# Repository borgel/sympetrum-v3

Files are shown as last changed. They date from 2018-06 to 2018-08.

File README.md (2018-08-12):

# What?
An electronic conference badge, of course! (That makes this a wearable right?)

If you're interested in keeping up to date with new versions, you can add your email here: 
https://goo.gl/forms/xGFPdRpdT4x1kmzG3 I'll send out (few) updates as I make progress towards whatever the next version is.

## Yes, but what does it do?
By default the device does pleasant RGB fades across its 48 RGB LEDs. It also sends a beacon in infrared every 30 seconds. They use any beacons received to synchronize a clock from which an animation is derived. The effect is that if one is alone, it plays random colors. If a group of them are together, they play the same rainbow water drop animation together.

For a little more information, last year's was [written up by Hackaday here](https://hackaday.com/2017/07/14/badge-from-diamond-age-comes-to-def-con/).

This is a partial rewrite of the work done for [DEFCON](https://defcon.org/) 25 ([here](https://github.com/borgel/sympetrum-v2)).

## Why is it a dragonfly?
If you haven't read Neal Stephenson's [_The Diamond Age: or, A Young Lady's Illustrated Primer_](http://www.goodreads.com/book/show/827.The_Diamond_Age), do that first. I'll wait.

If you have, there's a sequence around page 300 in which Miranda is first introduced to the possibility of using the drummers to find Nell. In this scene she attends a party in which the revellers wear colorful cloisonné dragonfly pins. As the party progresses they transition from random colorful flickering to some sort of synchrony, and Miranda notices the participants do the same. This is what I built.

A [_Sympetrum_](https://en.wikipedia.org/wiki/Sympetrum) is a genus of Dragonfly.

# Addons
Assembly instructions here: https://docs.google.com/document/d/1MZ-Gf56ivJ_pZaOBdA2XsJtWuKzQMPqqDXrGzq-pdRY/edit?usp=sharing

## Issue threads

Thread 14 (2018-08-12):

USB header for power?

f1ana, 2018-08-12:
Hi,

Do you have instructions for providing power to the dragonfly via usb?  Pretty new to this, so not sure where to start!

Thanks,
Chris

f1ana, 2018-08-14:
Hi!  I thought that this might be a great night light for my daughter and to perhaps change the LED patterns down the road.  I've only got a software background and very little to no hardware, so I'm not sure what the best/proper way to accomplish this would be.

borgel, 2018-08-15:
Oh, that's a great idea! I think it shouldn't be too bad. Do you have access to a soldering iron?

borgel, 2018-08-15:
I think you could remove the battery holder and install something like this https://www.sparkfun.com/products/8376 in it's place, wiring the 3.3v supply lines to where the batteries used to be. (I'm sure there are other options for the supply, this was just the fastest to find)

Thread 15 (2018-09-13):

Badge lights up intermittently, then dies

Gitoffomalawn, 2018-09-13:
I bought two dragonfly badge last DEFCON, but only got to turning the second one this week. There seems to be something wrong with it though:

When I turned it on for the first time (using the batteries that came with), it lit up for about two seconds and died. Trying to turn it on again failed. So I put it down for a few days.
After a few days, I tried again, same thing happened. Tried other batteries, but it still wouldn't turn on. I've tried three different sets of batteries so far, none worked.
The other badge works just fine with any of the batteries.

You have any ideas as to what might be going on, and what I can do to fix it?

borgel, 2018-09-14:
Hmm. Does it completely turn off?

Gitoffomalawn, 2018-09-28:
Sorry for my late reply.

Yes, it turns completely off. I gave it another try a few days back, and it turned on again only to turn off again after about an hour. New batteries did not solve the problem.

Whenever the badge does turn on, it seems to do so for a random amount of time, before shutting down. Then it won't turn back on, until having "rested" a few days (maybe hours, haven't tried measuring the time increments necessary). Then the problem repeats.

borgel, 2018-11-29:
Unfortunately I don't have any more information. My guess is that there was some damage to the power regulator (probably ESD?) at some point. It's on the small side, but there are only 6 pins. Do you have the tools/are you up to try a repair? I'm happy to send a few spares.

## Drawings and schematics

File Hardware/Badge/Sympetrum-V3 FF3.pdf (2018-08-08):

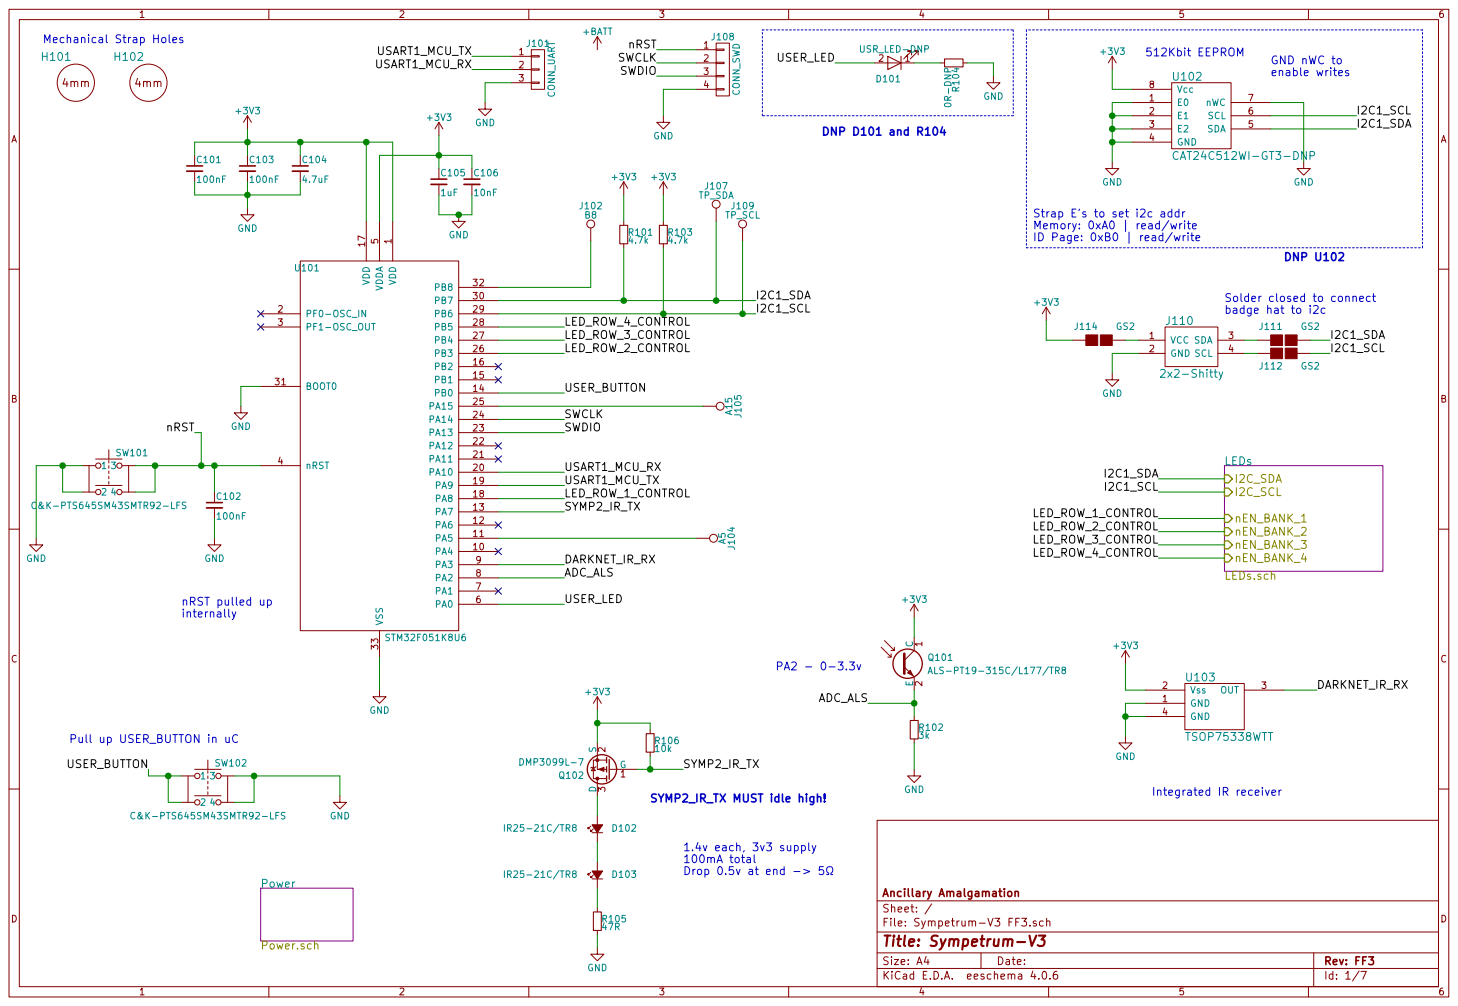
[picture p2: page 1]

enable writes GND Strap E's to set i2c addr

GND GND nWC to

badge hat to i2c DNP D101 and R104 C105

Memory: 0xA0 | read/write
ID Page: 0xB0 | read/write

Pull up USER_BUTTON in uC

1.4v each, 3v3 supply 100mA total Drop 0.5v at end -> 5

File: Sympetrum-V3 FF3.sch Sheet: / Ancillary Amalgamation

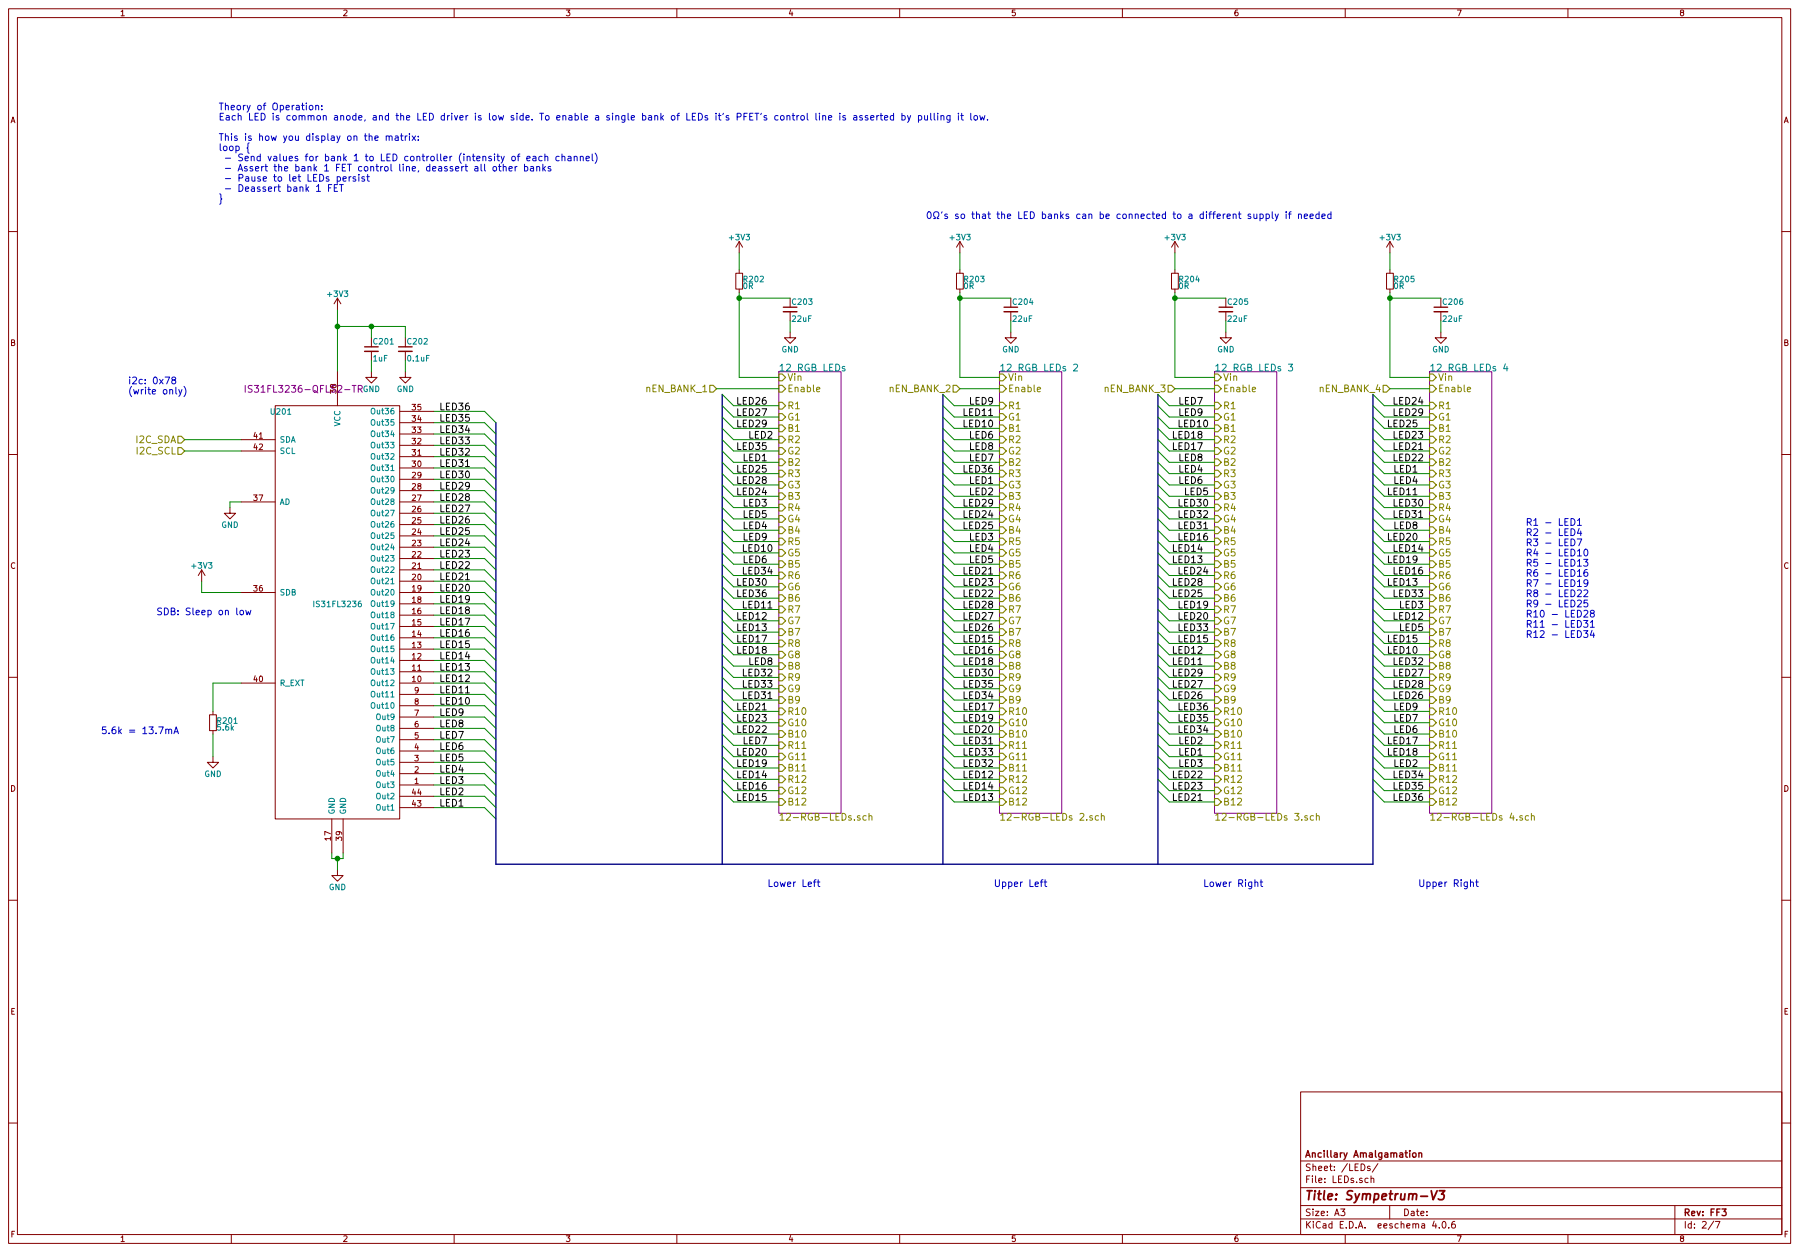
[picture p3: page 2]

Theory of Operation:
Each LED is common anode, and the LED driver is low side. To enable a single bank of LEDs it's PFET's control line is asserted by pulling it low.
This is how you display on the matrix:
loop {
- Send values for bank 1 to LED controller (intensity of each channel)
- Assert the bank 1 FET control line, deassert all other banks
- Pause to let LEDs persist
- Deassert bank 1 FET

12-RGB-LEDs.sch Enable Vin R1 G1 B1R2 G2 B2R3 G3 B3R4 G4 B4R5 G5 B5R6 G6 B6R7 G7 B7R8 G8 B8R9 G9 B9R10 G10 B10 R11 G11 B11 R12 G12 B12

12-RGB-LEDs 2.sch Enable Vin R1 G1 B1R2 G2 B2R3 G3 B3R4 G4 B4R5 G5 B5R6 G6 B6R7 G7 B7R8 G8 B8R9 G9 B9R10 G10 B10 R11 G11 B11 R12 G12 B12

12-RGB-LEDs 3.sch Enable Vin R1 G1 B1R2 G2 B2R3 G3 B3R4 G4 B4R5 G5 B5R6 G6 B6R7 G7 B7R8 G8 B8R9 G9 B9R10 G10 B10 R11 G11 B11 R12 G12 B12

12-RGB-LEDs 4.sch Enable Vin R1 G1 B1R2 G2 B2R3 G3 B3R4 G4 B4R5 G5 B5R6 G6 B6R7 G7 B7R8 G8 B8R9 G9 B9R10 G10 B10 R11 G11 B11 R12 G12 B12

File: LEDs.sch Sheet: /LEDs/ Ancillary Amalgamation

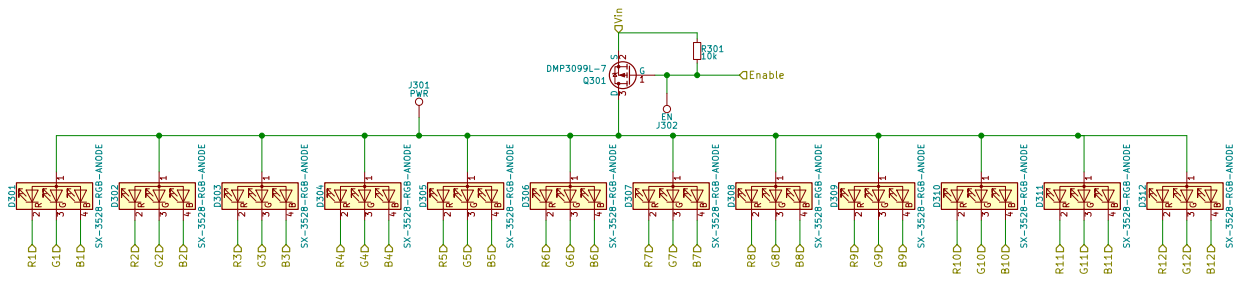
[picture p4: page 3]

4 D301 SX-3528-RGB-ANODE Vin RG

4 D303 SX-3528-RGB-ANODE RG

4 D304 SX-3528-RGB-ANODE RG

4 D305 SX-3528-RGB-ANODE RG

4 D306 SX-3528-RGB-ANODE RG

4 D307 SX-3528-RGB-ANODE RG

4 D308 SX-3528-RGB-ANODE RG

4 D309 SX-3528-RGB-ANODE RG

4 D310 SX-3528-RGB-ANODE RG

4 D311 SX-3528-RGB-ANODE RG

File: 12-RGB-LEDs.sch Sheet: /LEDs/12 RGB LEDs/ Ancillary Amalgamation

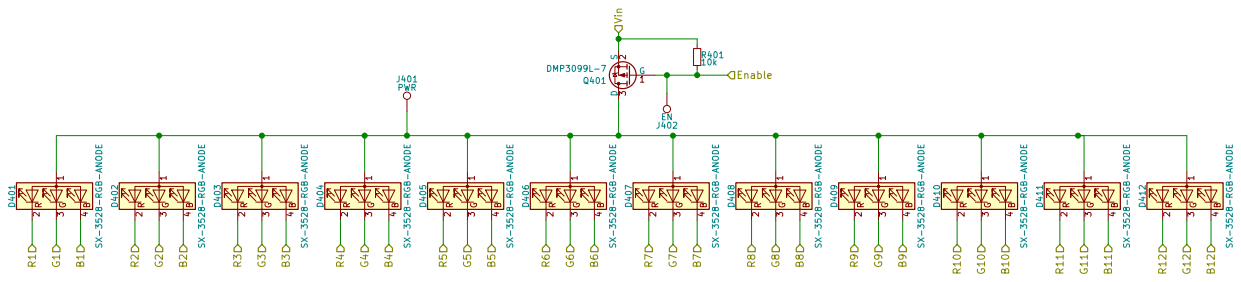
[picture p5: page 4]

4 D401 SX-3528-RGB-ANODE Vin

4 D402 SX-3528-RGB-ANODE RG

4 D403 SX-3528-RGB-ANODE RG

4 D404 SX-3528-RGB-ANODE RG

4 D405 SX-3528-RGB-ANODE RG

4 D406 SX-3528-RGB-ANODE RG

4 D407 SX-3528-RGB-ANODE RG

4 D408 SX-3528-RGB-ANODE RG

4 D409 SX-3528-RGB-ANODE RG

4 D410 SX-3528-RGB-ANODE RG

4 D411 SX-3528-RGB-ANODE RG

File: 12-RGB-LEDs 2.sch Sheet: /LEDs/12 RGB LEDs 2/ Ancillary Amalgamation

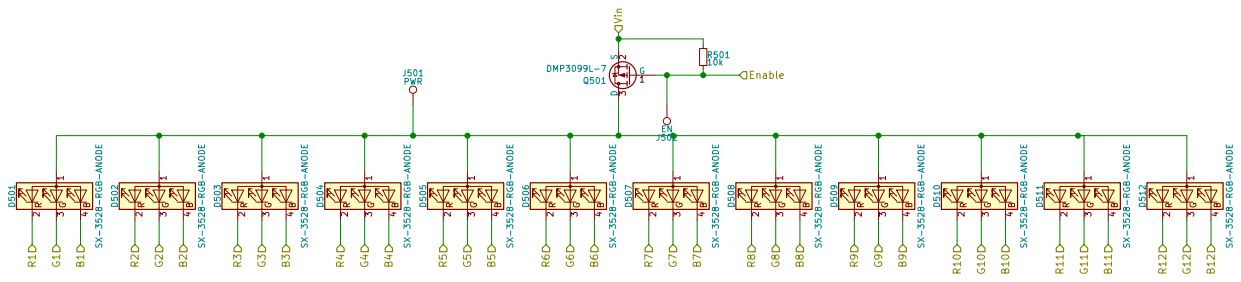
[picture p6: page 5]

4 D501 SX-3528-RGB-ANODE Vin

4 D502 SX-3528-RGB-ANODE RG

4 D503 SX-3528-RGB-ANODE RG

4 D504 SX-3528-RGB-ANODE RG

4 D505 SX-3528-RGB-ANODE RG

4 D506 SX-3528-RGB-ANODE RG

4 D507 SX-3528-RGB-ANODE RG

4 D508 SX-3528-RGB-ANODE RG

4 D509 SX-3528-RGB-ANODE RG

4 D510 SX-3528-RGB-ANODE RG

4 D511 SX-3528-RGB-ANODE RG

File: 12-RGB-LEDs 3.sch Sheet: /LEDs/12 RGB LEDs 3/ Ancillary Amalgamation

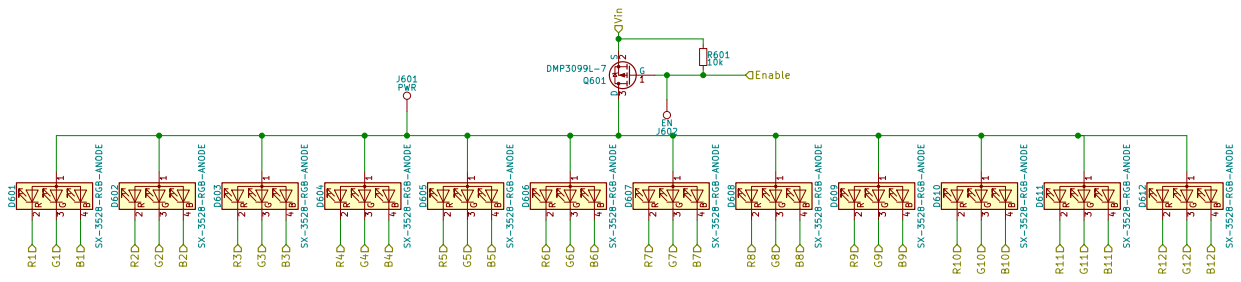
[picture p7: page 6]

4 D601 SX-3528-RGB-ANODE Vin

4 D602 SX-3528-RGB-ANODE RG

4 D603 SX-3528-RGB-ANODE RG

4 D604 SX-3528-RGB-ANODE RG

4 D605 SX-3528-RGB-ANODE RG

4 D606 SX-3528-RGB-ANODE RG

4 D607 SX-3528-RGB-ANODE RG

4 D608 SX-3528-RGB-ANODE RG

4 D609 SX-3528-RGB-ANODE RG

4 D610 SX-3528-RGB-ANODE RG

4 D611 SX-3528-RGB-ANODE RG

File: 12-RGB-LEDs 4.sch Sheet: /LEDs/12 RGB LEDs 4/ Ancillary Amalgamation

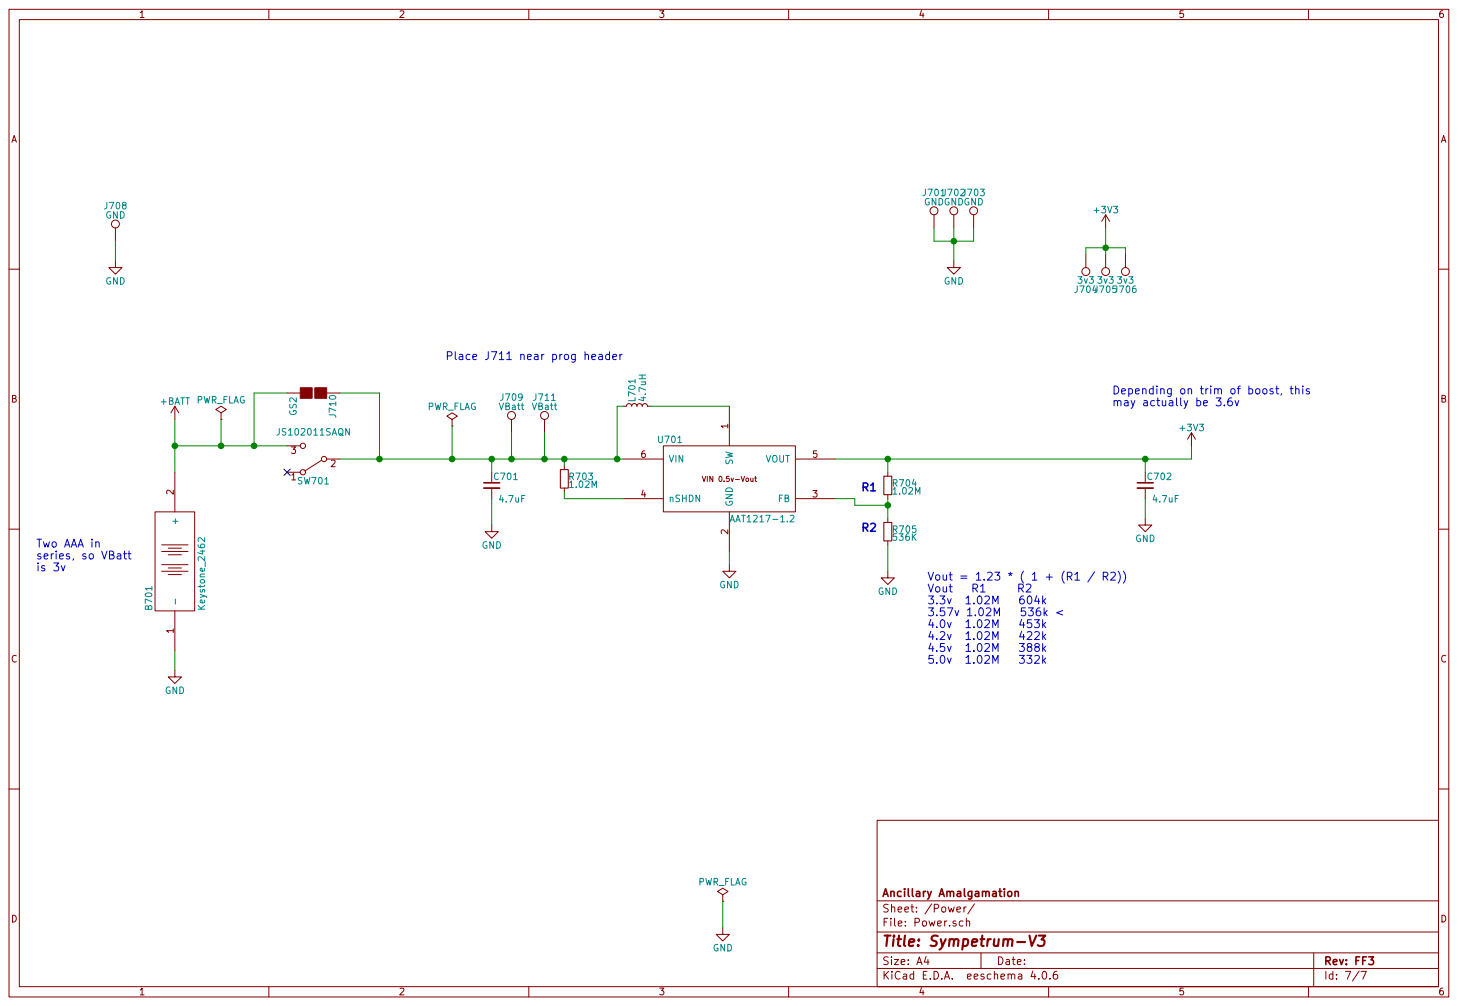
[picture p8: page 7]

File: Power.sch Sheet: /Power/ Ancillary Amalgamation C701

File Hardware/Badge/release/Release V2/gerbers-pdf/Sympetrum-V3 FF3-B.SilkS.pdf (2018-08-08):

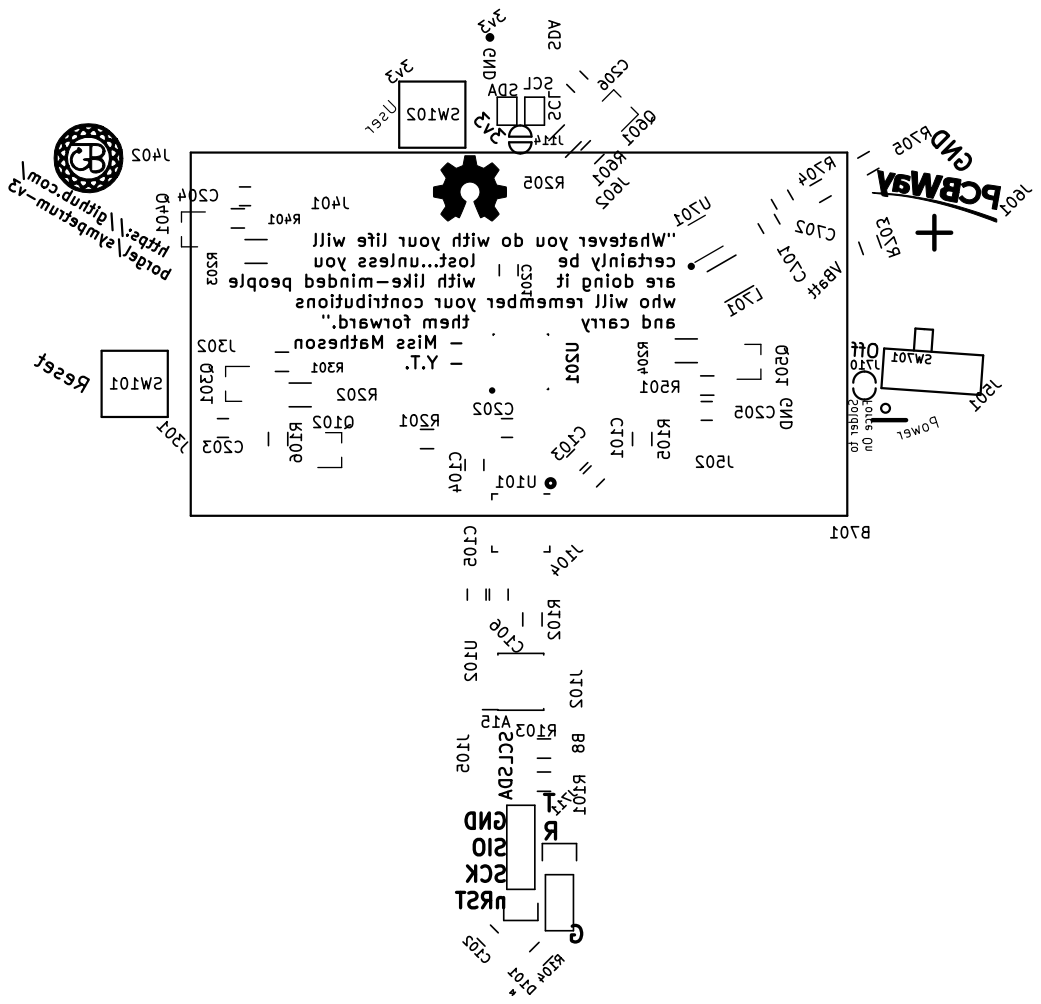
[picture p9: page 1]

Solder to Force On GND

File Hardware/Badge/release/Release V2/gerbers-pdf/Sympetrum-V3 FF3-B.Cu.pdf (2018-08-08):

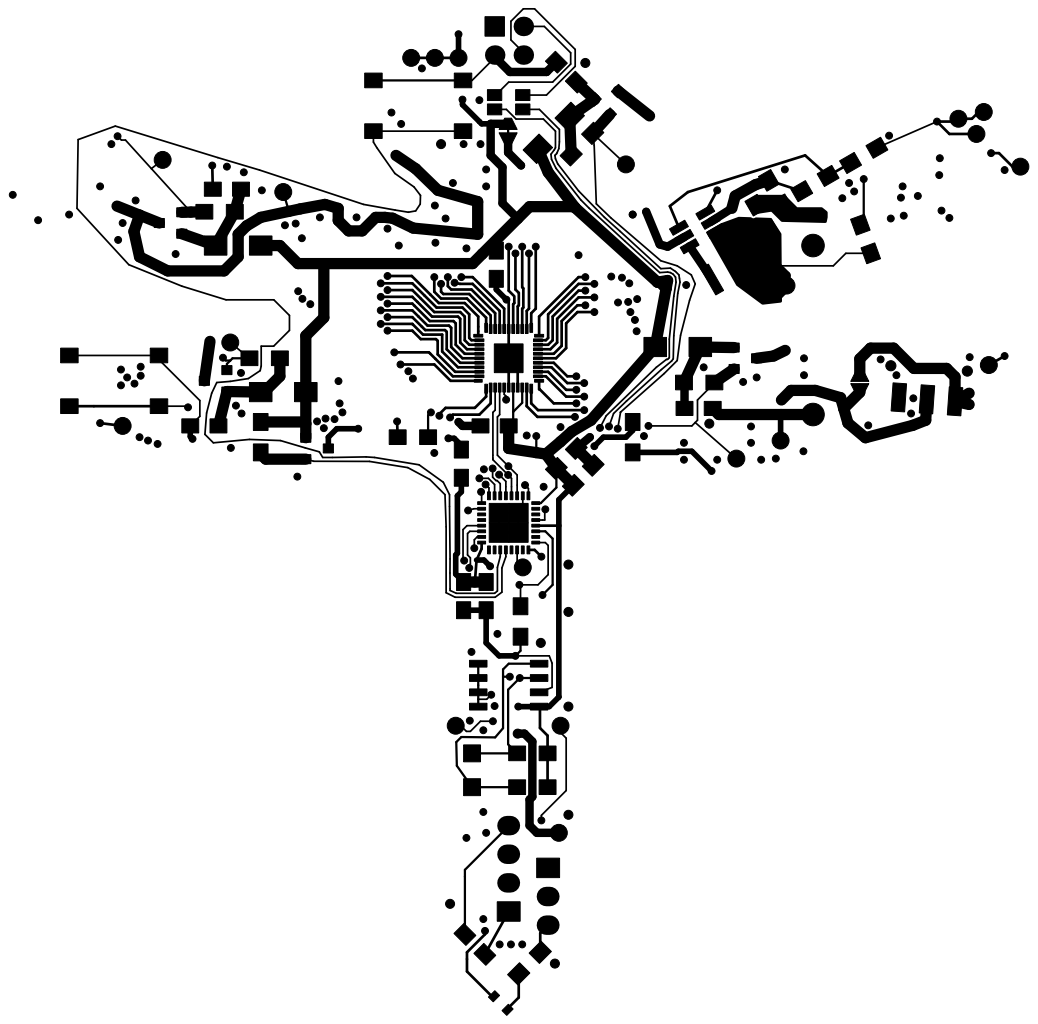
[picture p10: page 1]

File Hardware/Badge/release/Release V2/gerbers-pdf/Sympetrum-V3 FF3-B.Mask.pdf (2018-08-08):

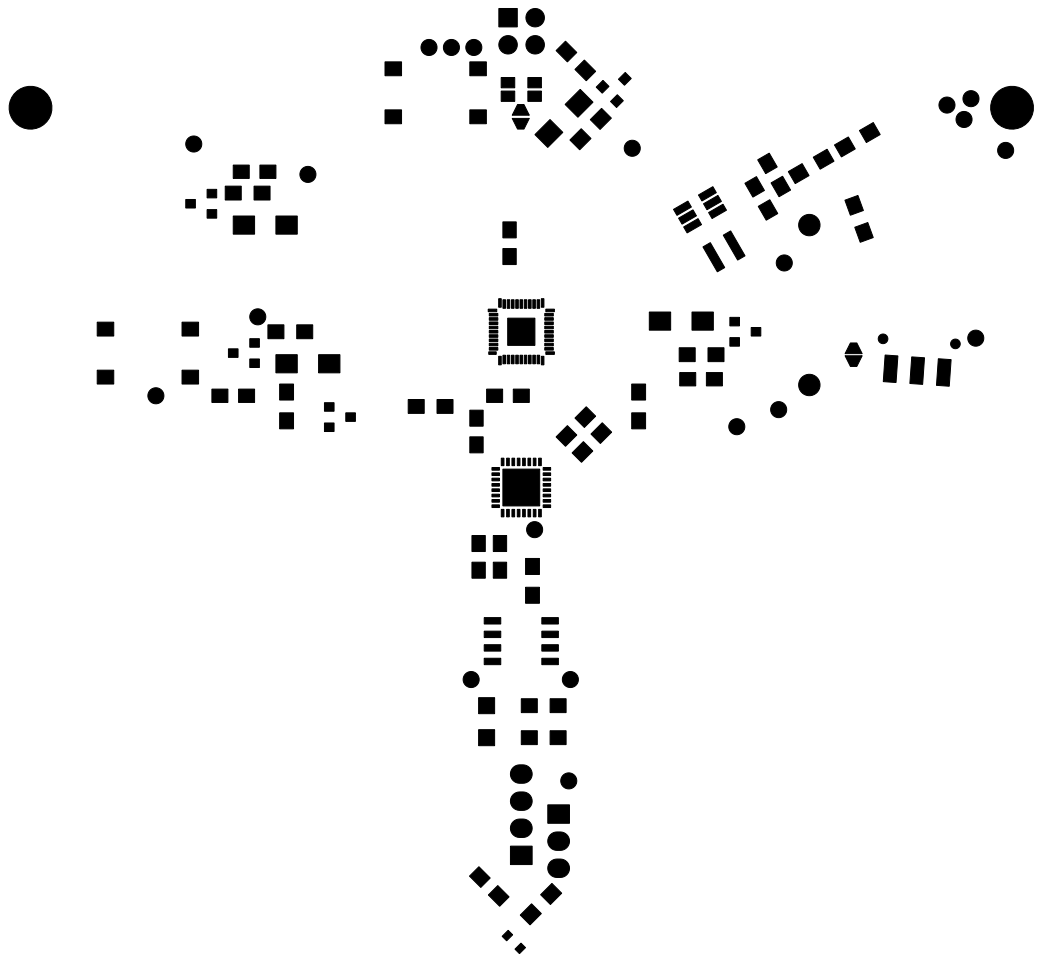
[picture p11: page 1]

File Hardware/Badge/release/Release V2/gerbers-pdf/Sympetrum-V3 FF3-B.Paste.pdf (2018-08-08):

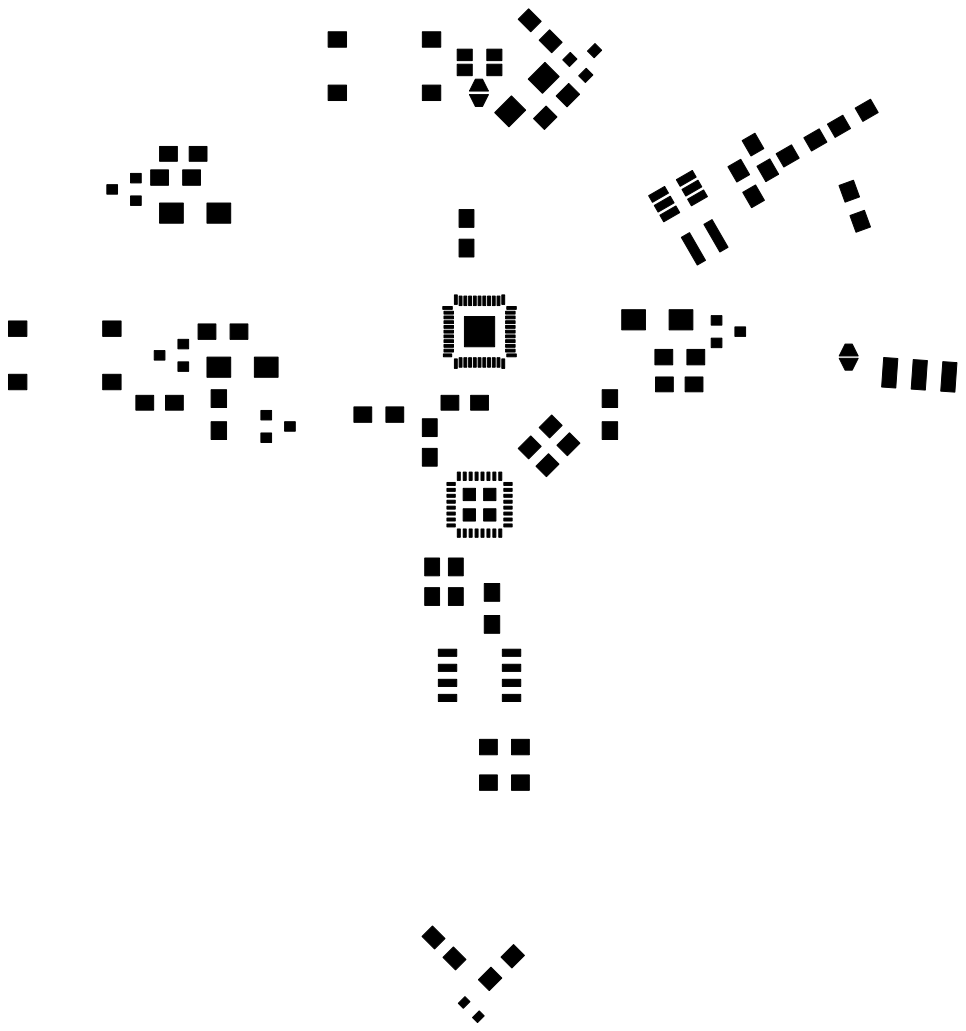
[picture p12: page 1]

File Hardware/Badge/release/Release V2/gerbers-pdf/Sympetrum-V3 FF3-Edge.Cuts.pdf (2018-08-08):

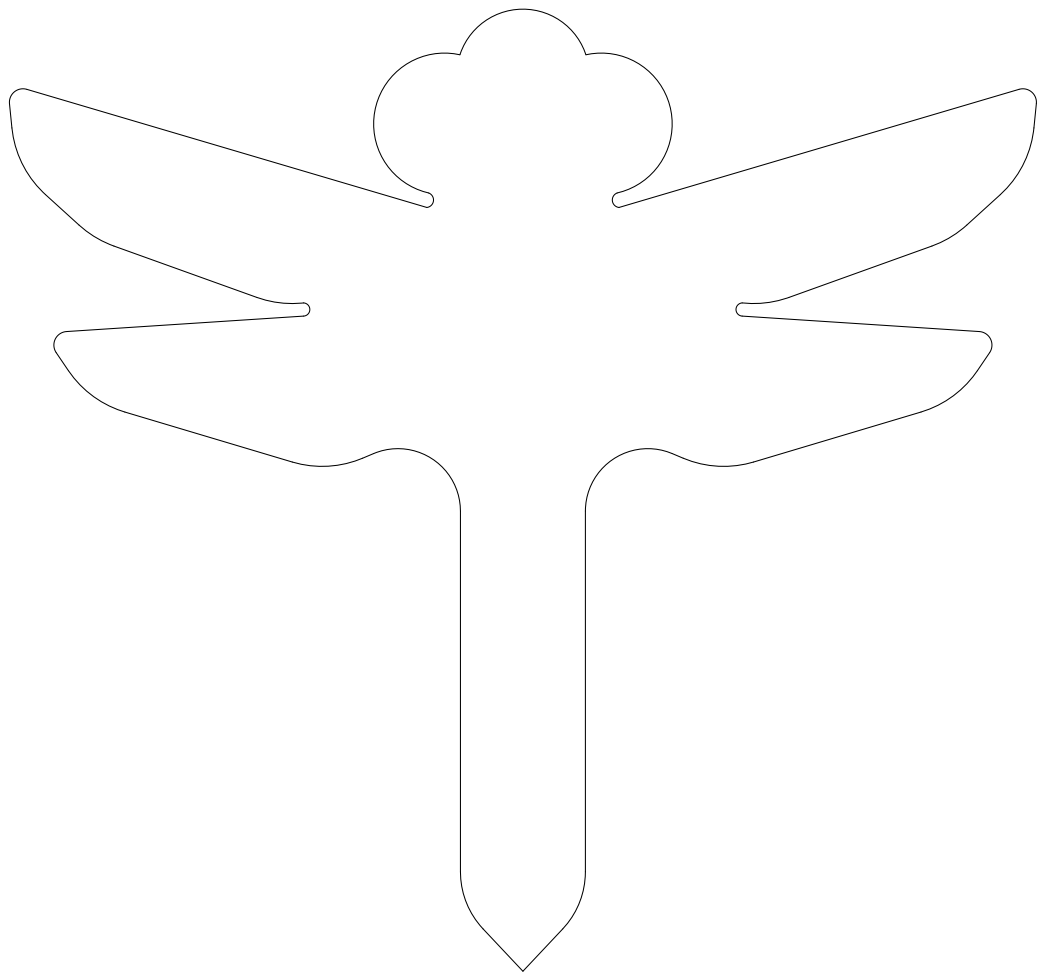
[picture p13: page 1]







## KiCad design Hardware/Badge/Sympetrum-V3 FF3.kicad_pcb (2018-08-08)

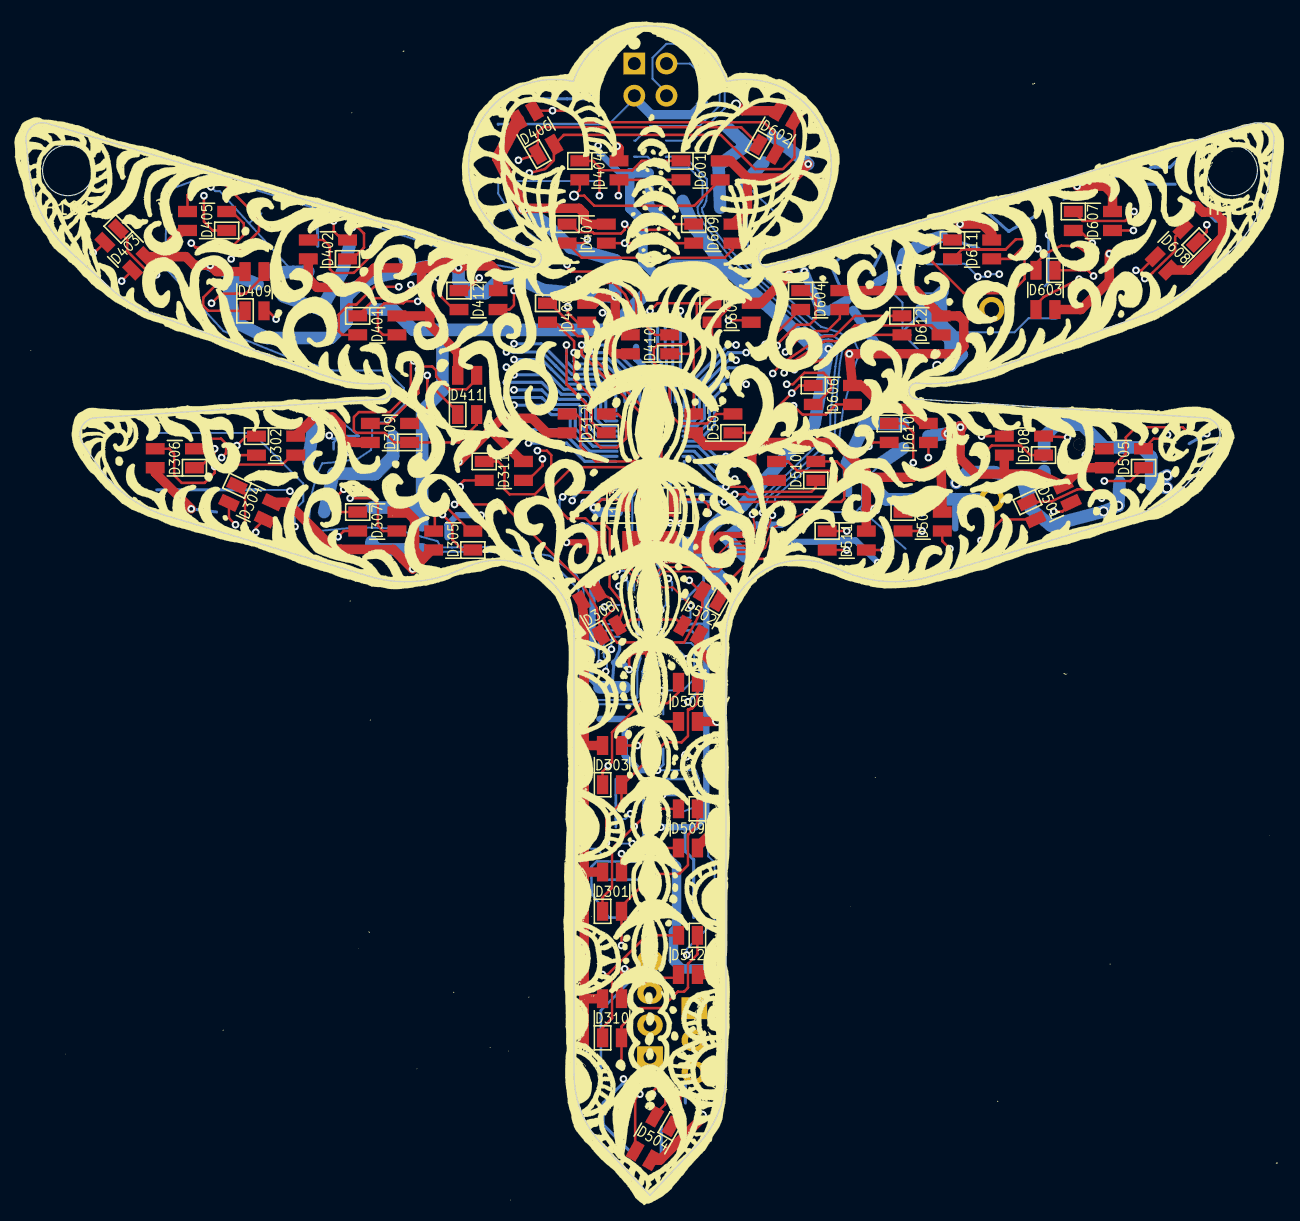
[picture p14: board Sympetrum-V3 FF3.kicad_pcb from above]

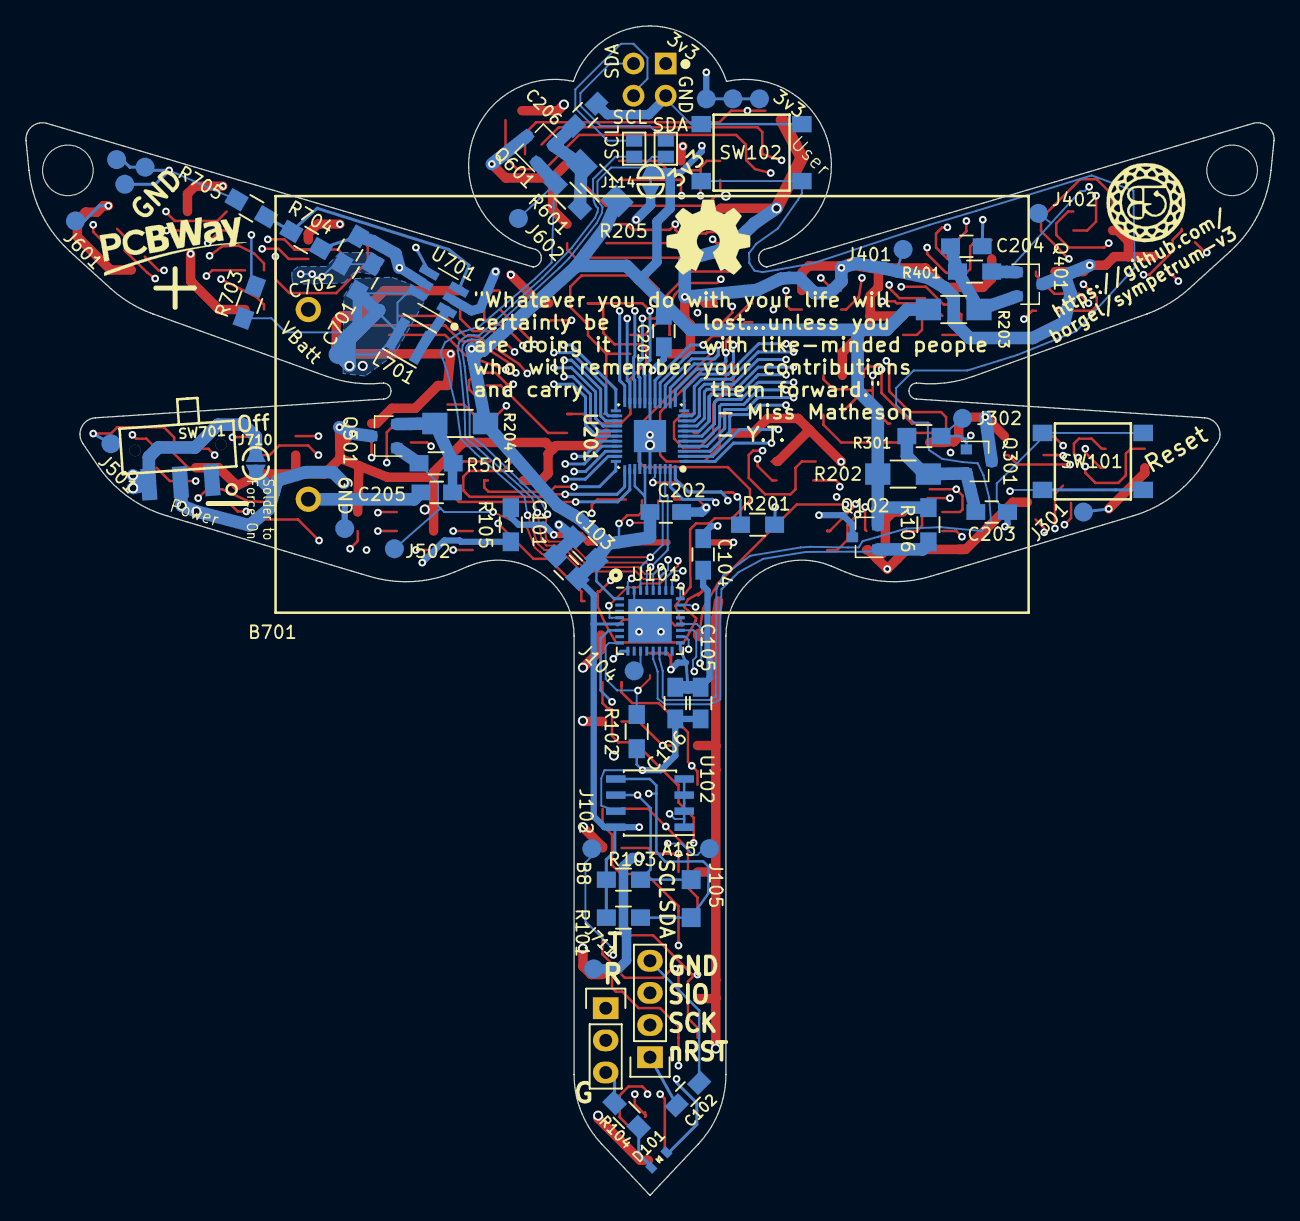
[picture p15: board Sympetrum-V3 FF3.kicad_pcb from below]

Board: 6 copper layers, 98.6 x 92.4 mm, 130 parts (75 on the bottom side), 78 nets.

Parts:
B701: Keystone_2462
C101, C102, C103: 100nF; C_0805_HandSoldering
C104, C701, C702: 4.7uF; C_0805_HandSoldering
C105, C201: 1uF; C_0805_HandSoldering
C106: 10nF; C_0805_HandSoldering
C202: 0.1uF; C_0805_HandSoldering
C203, C204, C205, C206: 22uF; C_0805_HandSoldering
D101: USR_LED-DNP; LED_0603_SmallSilk
D102, D103: IR25-21C/TR8; LED_1206_SmallSilk
D301, D302, D303, D304, D305, D306, D307, D308, D309, D310, D311, D312, D401, D402, D403, D404, D405, D406, D407, D408, D409, D410, D411, D412, D501, D502, D503, D504, D505, D506, D507, D508, D509, D510, D511, D512, D601, D602, D603, D604, D605, D606, D607, D608, D609, D610, D611, D612: SX-3528-RGB-ANODE; SX-3528-RGB-REORDERED-HiddenSilk
H101, H102: Hole-4mm-NPTH
J101: CONN_UART; Pin_Header_Straight_1x03
J102: B8; Measurement_Point_Round-SMD-Pad_Small
J104: A5; Measurement_Point_Round-SMD-Pad_Small
J105: A15; Measurement_Point_Round-SMD-Pad_Small
J107: TP_SDA; Measurement_Point_Square-SMD-Pad_Small
J108: CONN_SWD; Pin_Header_Straight_1x04
J109: TP_SCL; Measurement_Point_Square-SMD-Pad_Small
J110: 2x2-Shitty; 2x2_shitty
J111, J112: GS2
J114: GS2; SOLDER-JUMPER_1-WAY-SM-CLOSED
J301, J401, J501, J601: PWR; Measurement_Point_Round-SMD-Pad_Small
J302, J402, J502, J602: EN; Measurement_Point_Round-SMD-Pad_Small
J701, J702, J703, J708: GND; Measurement_Point_Round-SMD-Pad_Small
J704, J705, J706: 3v3; Measurement_Point_Round-SMD-Pad_Small
J709, J711: VBatt; Measurement_Point_Round-SMD-Pad_Small
J710: GS2; SOLDER-JUMPER_1-WAY-SM
L701: 4.7uH; Inductor_Taiyo-Yuden_MD-3030
Q101: ALS-PT19-315C/L177/TR8; LED_0603_SmallSilk
Q102, Q301, Q401, Q501, Q601: DMP3099L-7; SOT-23
R101, R103: 4.7k; R_0805_HandSoldering
R102: 3k; R_0805_HandSoldering
R104: 0R-DNP; R_0805_HandSoldering
R105: 47R; R_0805_HandSoldering
R106, R301, R401, R501, R601: 10k; R_0805_HandSoldering
R201: 5.6k; R_0805_HandSoldering
R202, R203, R204, R205: 0R; R_1206_HandSoldering
R703, R704: 1.02M; R_0805_HandSoldering
R705: 536K; R_0805_HandSoldering
SW101, SW102: C&K-PTS645SM43SMTR92-LFS; PTS645_SMT
SW701: JS102011SAQN; CK-JS102011SAQN_sm-spdt-switch
U101: STM32F051K8U6; QFN-32-1EP_5x5mm_Pitch0.5mm
U102: CAT24C512WI-GT3-DNP; SOIC-8_3.9x4.9mm_Pitch1.27mm
U103: TSOP75338WTT; TSOP753W
U201: IS31FL3236; QFN-44-5x5_Pitch0.4mm-Narrow
U701: AAT1217-1.2; SOT-23-6_Handsoldering

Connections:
+3V3: C101.1, C103.1, C104.1, C105.1, C106.1, C201.1, C202.1, C702.1, J114.1, J704.1, J705.1, J706.1, Q101.1, Q102.2, R101.1, R103.1, R106.1, R202.1, R203.1, R204.1, R205.1, R704.1, U101.1, U101.5, U101.17, U102.8, U103.2, U201.36, U201.38, U701.5
+BATT: B701.2, J710.2, SW701.3
/ADC_ALS: Q101.2, R102.1, U101.8
/DARKNET_IR_RX: U101.9, U103.3
/I2C1_SCL: J109.1, J112.2, R103.2, U101.29, U102.6, U201.42
/I2C1_SDA: J107.1, J111.2, R101.2, U101.30, U102.5, U201.41
/LED_ROW_1_CONTROL: J302.1, Q301.1, R301.2, U101.18
/LED_ROW_2_CONTROL: J402.1, Q401.1, R401.2, U101.26
/LED_ROW_3_CONTROL: J502.1, Q501.1, R501.2, U101.27
/LED_ROW_4_CONTROL: J602.1, Q601.1, R601.2, U101.28
/LEDs/12 RGB LEDs 2/Vin: C204.1, Q401.2, R203.2, R401.1
/LEDs/12 RGB LEDs 3/Vin: C205.1, Q501.2, R204.2, R501.1
/LEDs/12 RGB LEDs 4/Vin: C206.1, Q601.2, R205.2, R601.1
/LEDs/12 RGB LEDs/Vin: C203.1, Q301.2, R202.2, R301.1
/LEDs/LED1: D302.4, D403.3, D511.3, D603.2, U201.43
/LEDs/LED2: D302.2, D403.4, D511.2, D611.4, U201.44
/LEDs/LED3: D304.2, D405.2, D511.4, D607.2, U201.1
/LEDs/LED4: D304.4, D405.3, D503.2, D603.3, U201.2
/LEDs/LED5: D304.3, D405.4, D503.4, D607.4, U201.3
/LEDs/LED6: D305.4, D402.2, D503.3, D610.4, U201.4
/LEDs/LED7: D311.2, D402.4, D501.2, D610.3, U201.5
/LEDs/LED8: D308.4, D402.3, D502.4, D604.4, U201.6
/LEDs/LED9: D305.2, D401.2, D501.3, D610.2, U201.7
/LEDs/LED10: D305.3, D401.4, D501.4, D608.3, U201.8
/LEDs/LED11: D307.2, D401.3, D508.4, D603.4, U201.9
/LEDs/LED12: D307.3, D412.2, D508.3, D607.3, U201.10
/LEDs/LED13: D307.4, D412.4, D505.4, D606.3, U201.11
/LEDs/LED14: D312.2, D412.3, D505.3, D605.3, U201.12
/LEDs/LED15: D312.4, D408.2, D508.2, D608.2, U201.13
/LEDs/LED16: D312.3, D408.3, D505.2, D606.2, U201.14
/LEDs/LED17: D308.2, D410.2, D502.3, D611.2, U201.15
/LEDs/LED18: D308.3, D408.4, D502.2, D611.3, U201.16
/LEDs/LED19: D311.4, D410.3, D507.2, D605.4, U201.18
/LEDs/LED20: D311.3, D410.4, D507.3, D605.2, U201.19
/LEDs/LED21: D310.2, D406.2, D512.4, D602.3, U201.20
/LEDs/LED22: D310.4, D406.4, D512.2, D602.4, U201.21
/LEDs/LED23: D310.3, D406.3, D512.3, D602.2, U201.22
/LEDs/LED24: D303.4, D404.3, D506.2, D601.2, U201.23
/LEDs/LED25: D303.2, D404.4, D506.4, D601.4, U201.24
/LEDs/LED26: D301.2, D407.4, D509.4, D609.4, U201.25
/LEDs/LED27: D301.3, D407.3, D509.3, D609.2, U201.26
/LEDs/LED28: D303.3, D407.2, D506.3, D609.3, U201.27
/LEDs/LED29: D301.4, D404.2, D509.2, D601.3, U201.28
/LEDs/LED30: D306.3, D409.2, D504.2, D604.2, U201.29
/LEDs/LED31: D309.4, D411.2, D504.4, D604.3, U201.30
/LEDs/LED32: D309.2, D411.4, D504.3, D608.4, U201.31
/LEDs/LED33: D309.3, D411.3, D507.4, D606.4, U201.32
/LEDs/LED34: D306.2, D409.4, D510.4, D612.2, U201.33
/LEDs/LED35: D302.3, D409.3, D510.3, D612.3, U201.34
/LEDs/LED36: D306.4, D403.2, D510.2, D612.4, U201.35
/SWCLK: J108.2, U101.24
/SWDIO: J108.3, U101.23
/SYMP2_IR_TX: Q102.1, R106.2, U101.13
/USART1_MCU_RX: J101.2, U101.20
/USART1_MCU_TX: J101.1, U101.19
/USER_BUTTON: SW102.1, SW102.2, U101.14
/USER_LED: D101.2, U101.6
/nRST: C102.1, J108.1, SW101.3, SW101.4, U101.4
GND: B701.1, C101.2, C102.2, C103.2, C104.2, C105.2, C106.2, C201.2, C202.2, C203.2, C204.2, C205.2, C206.2, C701.2, C702.2, J101.3, J108.4, J110.2, J701.1, J702.1, J703.1, J708.1, R102.2, R104.1, R105.2, R201.2, R705.2, SW101.1, SW101.2, SW102.3, SW102.4, U101.31, U101.33, U102.1, U102.2, U102.3, U102.4, U102.7, U103.1, U103.4, U201.17, U201.37, U201.39, U701.2
unnamed: C701.1, J709.1, J710.1, J711.1, L701.1, R703.1, SW701.2, U701.6
unnamed: D101.1, R104.2
unnamed: D102.1, D103.2
unnamed: D102.2, Q102.3
unnamed: D103.1, R105.1
unnamed: D301.1, D302.1, D303.1, D304.1, D305.1, D306.1, D307.1, D308.1, D309.1, D310.1, D311.1, D312.1, J301.1, Q301.3
unnamed: D401.1, D402.1, D403.1, D404.1, D405.1, D406.1, D407.1, D408.1, D409.1, D410.1, D411.1, D412.1, J401.1, Q401.3
unnamed: D501.1, D502.1, D503.1, D504.1, D505.1, D506.1, D507.1, D508.1, D509.1, D510.1, D511.1, D512.1, J501.1, Q501.3
unnamed: D601.1, D602.1, D603.1, D604.1, D605.1, D606.1, D607.1, D608.1, D609.1, D610.1, D611.1, D612.1, J601.1, Q601.3
unnamed: J102.1, U101.32
unnamed: J104.1, U101.11
unnamed: J105.1, U101.25
unnamed: J110.1, J114.2
unnamed: J110.3, J111.1
unnamed: J110.4, J112.1
unnamed: L701.2, U701.1
unnamed: R201.1, U201.40
unnamed: R703.2, U701.4
unnamed: R704.2, R705.1, U701.3

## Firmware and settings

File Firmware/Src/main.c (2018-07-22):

#include "platform_hw.h"
#include "iprintf.h"

#include "pattern.h"
#include "lighting.h"
#include "board_id.h"
#include "test.h"
#include "version.h"
#include "test_patterns.h"

// pull in the interpolator just for showing version on boot
#include "yabi/yabi.h"

#include <stdlib.h>

#define VERSION_FADE_SPEED_MS 500

#define BUTTON_DEBOUNCE_MS    150
static uint32_t lastUserButton = 0;

// indicate if we are in test mode
static bool TestMode = false;
static bool TestModeLED = false;

static void VersionToLEDs(bool invert);

int main(void)
{
   HAL_Init();

   platformHW_Init();

   iprintf("\r\nStarting... (v%d | #0x%x / 0x%x | Built "__DATE__":"__TIME__")\r\n", FW_VERSION, bid_GetID(), bid_GetIDCrc());

   // seed the PRNG from the kinda unique board ID
   srand(bid_GetID());

   // if we should enter test mode, do that
   if(test_EnterTestMode()) {
      TestMode = true;

      // this should never return
      test_DoTests();
   }
   TestMode = false;

   lighting_Init();

   // show version on LEDs before real animations take over
   VersionToLEDs(false);
   VersionToLEDs(true);

   pattern_Init();

   //TODO enter on boot if button held down
   // fall into LED test patterns forever
   //TestModeLED = true;
   //TestPatterns_Start();

   while(true) {
      // handle the button
      if(lastUserButton && (HAL_GetTick() - lastUserButton > BUTTON_DEBOUNCE_MS)) {
         lastUserButton = 0;

         iprintf("Button Pressed\n");
         pattern_DoSendBeacon();
      }

      pattern_Timeslice(HAL_GetTick());
      lighting_Timeslice(HAL_GetTick());
   }

   return 0;
}
/*
 * Write this unit's SW version to the LEDs once.
 */
static void VersionToLEDs(bool invert) {
   struct color_ColorHSV c;

   uint8_t colorSet = rand();
   uint8_t colorCleared = colorSet + 127;
   if(invert) {
      uint8_t e = colorCleared;
      colorCleared = colorSet;
      colorSet = e;

      colorCleared++;
      colorSet++;
   }

   iprintf("Displaying version on LEDs...");

   //unpack each bit, and set the Blue LED channel to it
   uint32_t mask = 0x01;
   for(int i = 0; i < TOTAL_LOGICAL_LEDS; i++) {
      // set the channel to 100 counts if the bit is set, 0 otherwise
      c.h = (mask & FW_VERSION) ? colorSet: colorCleared;
      c.s = 100;
      c.v = 100;

      lighting_DrawPixelLinear(i, &c, 0, VERSION_FADE_SPEED_MS);

      // only move the mask if we are within the size of the version var
      if(i < 8 * sizeof(FW_VERSION)) {
         mask <<= 1;
      }

   }

   uint32_t startTime = HAL_GetTick();
   while(HAL_GetTick() - startTime < VERSION_FADE_SPEED_MS) {
      yabi_giveTime(HAL_GetTick());
   }

   iprintf("Done\n");
}

void main_DoButton(bool const buttonPressed) {
   if(TestMode) {
      test_UserButton(buttonPressed);
   }
   else if(TestModeLED) {
      if(buttonPressed) {
         TestPatterns_Button();
      }
   }
   else {
      // running the normal program
      if(lastUserButton == 0 && buttonPressed) {
         lastUserButton = HAL_GetTick();
      }
   }
}

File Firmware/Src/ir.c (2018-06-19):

/*
 * ir.c
 *
 *      IR protocol based on DEFCON Darknet IR Library. Theory of operation adapted
 *      from that. Once place to find a copy of that lib is on their Github:
 *      https://github.com/thedarknet/defcon25-badge/blob/master/software/firmware/src/badge/ir.cpp
 *
 *      Theory of operation:
 *      The IR tx/rx library encodes data using pulse widths modulated at 38kHz
 *
 *      A bit is encoded by a 'mark' and a 'space'.
 *
 *      A mark is always the same width during transmission, but the space
 *      changes width depending on whether the bit is a zero (short space)
 *      or one (long space).
 *
 *      A transmission is delimited by a start/stop pulse which consists of
 *      a longer 'mark' followed by a space. Every transmission starts and ends
 *      with the long marks.
 *
 *      During a transmit, a mark consists of modulated 38kHz signal. A space
 *      is the absence of that signal. During a receive, a mark consists of
 *      0V and a space is 3.3V. This is due to the Vishay TSOP receivers which
 *      have active-low outputs.
 *
 *      TIM17 Ch1 is used to generate the 38kHz signal on IR_TX_Pin
 *      and is connected to a pair of IR LEDs and a resistor in series.
 *      Enabling the TIM17 PWM generates the square wave which is intpreted as a
 *      "1". Disabling it "sends" a "0".
 *
 *      TIM3 is used as a timer to generate spaces and marks of particular
 *      widths during transmission. During reception, TIM3 is used to measure
 *      the incoming pulse widths.
 *
 */

#include "ir.h"
#include "ir_test.h"
#include "platform_hw.h"
#include "iprintf.h"
#include "stm32f0xx_hal.h"
#include "stm32f0xx_hal_tim.h"
#include "stm32f0xx_hal_gpio.h"
#include <stdlib.h>
#include <stdint.h>

// Number of TIM3 ticks for mark/space/start pulses
#define TICK_BASE (400)
#define MARK_TICKS (TICK_BASE)
#define START_TICKS (TICK_BASE * 2)
#define SPACE_ZERO_TICKS (TICK_BASE)
#define SPACE_ONE_TICKS (TICK_BASE * 3)

// Margin to account for time delay in measuring input pulses during receive
#define RX_MARGIN (TICK_BASE/2)

// RX Buffer size
#define IR_RX_BUFF_SIZE (256)

// type for internal CRC calculations
typedef uint8_t crc_t;

// States for state machine
typedef enum {
   IR_RX_IDLE = 0,
   IR_RX_START = 1,
   IR_RX_MARK_START = 2,
   IR_RX_MARK = 3,
   IR_RX_SPACE = 4,
   IR_RX_DONE = 5,
   IR_RX_ERR = -1,
   IR_RX_ERR_TIMEOUT = -2,
   IR_RX_ERR_OVERFLOW = -3,
   IR_RX_ERR_CRC = -4
} IRState_t;

typedef enum {
   IR_RX = 0, IR_TX
} IRMode_t;

static bool isInit = false;
static volatile IRState_t IRState;
static volatile IRMode_t IRMode;
static volatile uint8_t irRxBuff[IR_RX_BUFF_SIZE];
static volatile uint32_t irRxBits;
static volatile crc_t crc;
static bool ShouldRX = false;
static bool rxError = false;

TIM_HandleTypeDef htim3;
static TIM_HandleTypeDef htim17;

//TODO macro over TIM17 channel for PWM

static void TIM17_Init(void);
static void IRStartRx();
static bool IRStopRX();

static crc_t crc_init(void);
static crc_t crc_finalize(crc_t crc);
static crc_t crc_update(crc_t crc, const void *data, size_t data_len);

//
// Configure timer 3 to measure incoming IR pulse widths
// 48MHz clock divided by 32 gives us 1.5MHz timer clock
// With a 4096 period, timer overflows in ~2.73ms
//
static void TIM3_Init() {

   TIM_ClockConfigTypeDef sClockSourceConfig;

   __HAL_RCC_TIM3_CLK_ENABLE();

   htim3.Instance = TIM3;
   htim3.Init.Prescaler = 32;
   htim3.Init.CounterMode = TIM_COUNTERMODE_UP;
   htim3.Init.Period = 4096;
   htim3.Init.ClockDivision = TIM_CLOCKDIVISION_DIV1;
   HAL_TIM_Base_Init(&htim3);

   sClockSourceConfig.ClockSource = TIM_CLOCKSOURCE_INTERNAL;
   HAL_TIM_ConfigClockSource(&htim3, &sClockSourceConfig);

   __HAL_TIM_CLEAR_FLAG(&htim3, TIM_SR_UIF);
}

/*
 * Generated the 38kHz output signal when PWM is enabled
 */
static void TIM17_Init(void)
{
   TIM_OC_InitTypeDef sConfigOC;
   TIM_BreakDeadTimeConfigTypeDef sBreakDeadTimeConfig;

   htim17.Instance = TIM17;
   htim17.Init.Prescaler = 0;
   htim17.Init.CounterMode = TIM_COUNTERMODE_UP;
   htim17.Init.Period = 1333;
   htim17.Init.ClockDivision = TIM_CLOCKDIVISION_DIV1;
   htim17.Init.RepetitionCounter = 0;
   htim17.Init.AutoReloadPreload = TIM_AUTORELOAD_PRELOAD_ENABLE;
   if (HAL_TIM_Base_Init(&htim17) != HAL_OK)
   {
      iprintf("Error\r\n");
      return;
   }

   if (HAL_TIM_PWM_Init(&htim17) != HAL_OK)
   {
      iprintf("Error\r\n");
      return;
   }

   sConfigOC.OCMode = TIM_OCMODE_PWM1;
   sConfigOC.Pulse = 333;
   sConfigOC.OCPolarity = TIM_OCPOLARITY_HIGH;
   sConfigOC.OCNPolarity = TIM_OCNPOLARITY_HIGH;
   sConfigOC.OCFastMode = TIM_OCFAST_DISABLE;
   sConfigOC.OCIdleState = TIM_OCIDLESTATE_RESET;
   sConfigOC.OCNIdleState = TIM_OCNIDLESTATE_RESET;
   if (HAL_TIM_PWM_ConfigChannel(&htim17, &sConfigOC, TIM_CHANNEL_1) != HAL_OK)
   {
      iprintf("Error\r\n");
      return;
   }

   sBreakDeadTimeConfig.OffStateRunMode = TIM_OSSR_DISABLE;
   sBreakDeadTimeConfig.OffStateIDLEMode = TIM_OSSI_DISABLE;
   sBreakDeadTimeConfig.LockLevel = TIM_LOCKLEVEL_OFF;
   sBreakDeadTimeConfig.DeadTime = 0;
   sBreakDeadTimeConfig.BreakState = TIM_BREAK_DISABLE;
   sBreakDeadTimeConfig.BreakPolarity = TIM_BREAKPOLARITY_HIGH;
   sBreakDeadTimeConfig.AutomaticOutput = TIM_AUTOMATICOUTPUT_DISABLE;
   if (HAL_TIMEx_ConfigBreakDeadTime(&htim17, &sBreakDeadTimeConfig) != HAL_OK)
   {
      iprintf("Error\r\n");
      return;
   }
}

// Wait until a specified number of TIM3 clock ticks elapses
static void delayTicks(uint32_t ticks) {
   uint32_t oldTicks = TIM3->ARR; // Save value to be restored later

   IRMode = IR_TX; // Change mode so the TIM3 isr knows what to do

   // Make sure the timer isn't running anymore
   HAL_TIM_Base_Stop_IT(&htim3);

   TIM3->CNT = 0;
   TIM3->ARR = ticks;

   // Clear any pending interrupts and start counting!
   __HAL_TIM_CLEAR_FLAG(&htim3, TIM_SR_UIF);
   HAL_TIM_Base_Start_IT(&htim3);

   // Wait here until the timer overflow interrupt occurs
   while (IRMode == IR_TX) {
      __WFI();
   }

   // Restore auto reload register
   TIM3->ARR = oldTicks;
}

// Start TIM3 to measure incoming pulse width
static void startIRPulseTimer() {
   TIM3->CNT = 0;
   __HAL_TIM_CLEAR_FLAG(&htim3, TIM_SR_UIF);
   HAL_TIM_Base_Start_IT(&htim3);
}

static void stopIRPulseTimer() {
   HAL_TIM_Base_Stop_IT(&htim3);
}

void HAL_TIM_PeriodElapsedCallback(TIM_HandleTypeDef *htim) {
   if (htim == &htim3) {
      stopIRPulseTimer();
      if (IRMode == IR_RX) {
         // Timed out :(
         IRState = IR_RX_ERR_TIMEOUT;
      } else if (IRMode == IR_TX) {
         IRMode = IR_RX;
      }
   }
}
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

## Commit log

2017-12-04 Add test code
    Based on https://github.com/borgel/tomato-timer
2017-12-16 SQME not working starting toi integrate symp-v2 IR
    [main.c]
2018-02-02 Start a simple LED test function
2018-02-02 Very rough first draft matrix driver
2018-02-03 Blank during matrix scan to avoid ghosting
    [led.c]
2018-02-03 Generate an 80Hz interrupt on TIM14
2018-02-03 Bump to 100Hz
2018-02-03 Make LED controller row writes also force a display update
2018-02-03 Disable blanking, turns out it doesn't matter if the display is mostly always on
    [led.c]
2018-02-03 Reduce printing on LED init
2018-02-03 Move timer debug pin to PA5
2018-02-03 Factor matrix draw into a state machine and pump it from a timer at 100Hz
2018-02-03 Speed matrix timer up to 1kHz
2018-02-03 Get darknet to compile but not work
    [ir.c, main.c, platform_hw.h]
2018-02-03 Remove most debug printing from IR TX pipe
2018-02-07 Improve IR pin macros
2018-02-07 Add test code for user button
2018-02-09 Add ADC drivers to the HAL
2018-02-09 Add (working!) first draft ADC code for ALS
2018-03-15 Add pin defs for new TPs
2018-03-15 Move user button to match FF1
2018-03-15 Assert power enable pin at boot
2018-03-15 Handle test fails by spinning forever
    [test.c]
2018-03-15 Check if user button is idling properly
2018-03-15 Fix improperly called draw pixel
    [test.c]
2018-03-15 Remap user button interrupt and handler
2018-03-15 Fix global R/G/B hue defines
    [test.c]
2018-03-21 Add LED matrix commands to pause and resume it
2018-03-21 Stop LED matrix draw while TXing IR
2018-04-14 Add an LED test header to expose internal functions for tests
2018-04-14 Integrate per-bank LED tests
2018-04-14 Move LED channel and matrix info into platform_hw
2018-04-14 Begin mapping physical to logical LED channels
2018-04-15 Added test code to light single LEDs
2018-04-16 Update test LED draw to use new matrix mapping
2018-04-25 WIP trying to fix mapping
    [led.c, main.c, matrix_assignments.h]
2018-04-27 WIP Fixed raw array indexing!
    [led.c]
2018-04-28 WIP fix original pointer math ch assignments
    [led.c]
2018-04-29 Add all LED bank mapping (tested working)
2018-04-29 Fix bank map spacing
    [matrix_assignments.h]
2018-04-30 Remove unneeded LED channel macro
2018-04-30 Make user button interrupt on both edges
2018-04-30 Update user button handling to happen more in main
2018-04-30 Default LED global brightness to 100%
2018-04-30 WIP print ALS
2018-04-30 Track if system is in test mode and forward button presses to test module if so
2018-04-30 Track if user button has been pressed in test mode
2018-04-30 Add the notion of a test plan, and run different tests on button press
2018-05-01 Fix IR TX GPIO configuration
    There is a pull up on board, but let's be absolutely sure.
2018-05-01 Make the first test plan item reset state
    [test.c]
2018-05-01 Track the number of tests to run and number of completed cycles
2018-05-01 Remove old test failed fxn
    [test.c]
2018-05-01 Plumb GPIO interrupts on B8 into test module and handle them like a button
2018-05-01 Add a handy wrapper for setting test fixture LEDs
    [test.c]
2018-05-01 Track if test mode is active
2018-05-01 Track test passthrough flag better
2018-05-01 Handle interrupt events, track test pass, set pass/fail LEDs
    [test.c]
2018-05-11 Start debugging test code with fixture
    [platform_hw.c, test.c]
2018-05-12 Break LED map init into a function
2018-05-12 Add a field to the LED mapping struct to store logical linear position
2018-05-12 Add test code to do chasing LEDs, parallel top to bottom
2018-05-12 Fill in sparse matrix with LED coordinates
2018-05-15 Try a COS table for LED fade
2018-05-17 Better button handling in main and move LED test patterns into a file
2018-05-17 Add PDF reference for LED mapping
2018-05-20 Convert ALS intensity into brightness buckets
2018-05-21 Pull in simple timer code from Tomato Timer v2
2018-05-21 Start a simple timer to track beacon intervals
2018-05-24 WIP Start adding very rough animation framework
2018-05-30 Pass a duration into YABI interpolated LED setting
2018-05-30 Add jitter parameter to LED channel set commands
2018-05-30 Remove deprecated LED APIs
2018-05-30 CIE correct all LED drawing
    [led.c]
2018-05-31 Add an "interaction ramp" to govern how the animation behaves as the device interacts
2018-05-31 Pretend to send a beacon when user presses a the button
2018-06-02 Disable printing during IR send
2018-06-02 Make sure LED APIs are safe to call before pattern starts
2018-06-03 Adjust LED brightness fxn to take a global divisor
2018-06-03 Adjust LED brightness based on light level
2018-06-03 Mark deprecated LED control functions as static
2018-06-03 Fix ALS level type name
    [als.c]
2018-06-03 When moving along the animation ramp, slew jitter
2018-06-03 WIP send LED i2c with interrupts
2018-06-05 Use a little state machine and fix descoping buffer problem with i2c IT
    [led.c]
2018-06-09 Don't disable LEDs during IR TX
    Prevents glitching. Doesn't seem to effect IR reliability.
    [ir.c, main.c]
2018-06-09 Seed PRNG with board ID on boot
2018-06-10 LERP frame rate when changing it
2018-06-10 WIP fixing IR RX
    [ir.c]
2018-06-10 Temporarily switch to short beacon messages to improve reliablilty
2018-06-10 Set a flag if there was an RX error and reinit when we notice
    [ir.c]
2018-06-14 Don't init timers with pending completions
2018-06-14 Update animation timer when slewing framerate, not jitter
2018-06-14 Speed up jitter ramp
2018-06-14 Change timer set API to take a flag to reset timer or not
    [terrible_timer.c]
2018-06-14 When sending a beacon, set jitter to 0 for a moment
    Looks like a send animation
2018-06-16 Switch then disable going to inverse jitter on beacon
2018-06-19 On ramp, add a little timing jitter
2018-06-19 Properly configure TP B8 to not trigger random interrupts
2018-06-19 Check only user button to enter tests on boot
2018-06-19 Show IR test result on LED banks
2018-06-23 Show IR test result on a different bank
    Don't want it to show up where the first LED test bank is.
2018-06-23 Reorder LED tests to start with blue
    So IR test results (red/green) can't be confused with LED tests.
2018-06-23 Show firmware version on LEDs at boot
2018-07-04 Set version LEDs so they are always dissimilar
2018-07-04 Reset to recover the system if LED controller init fails
    [led.c]
2018-08-08 Add hardware sources
    [12-RGB-LEDs 2.sch, 12-RGB-LEDs 3.sch, 12-RGB-LEDs 4.sch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]
2018-08-08 Add a link to addon assembly instructions to README
